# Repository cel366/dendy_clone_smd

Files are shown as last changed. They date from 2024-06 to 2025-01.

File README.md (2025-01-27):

# Деndи
Конструкция 8-ми битной приставки ,клона famicom. Максимально элементы применены для поверхностного монтажа . Печатная плата разработана для изготовления в домашних условиях ,поэтому для соединения дорожек на разных слоях использованы переходные отверстия ,для соединениями перемычками .  в папке FAB/lut два файла svg  с слоями верхним(уже от зеркаленным) и нижним  

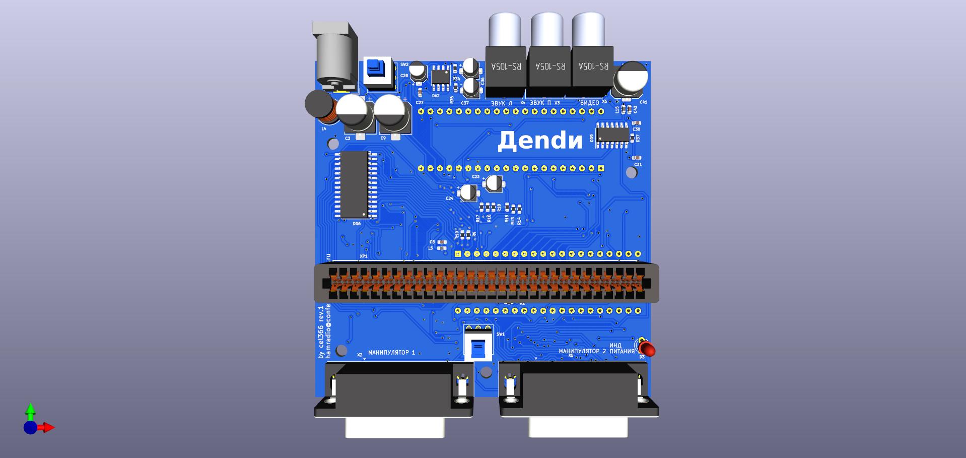
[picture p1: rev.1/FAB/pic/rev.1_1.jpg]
rev.1_1

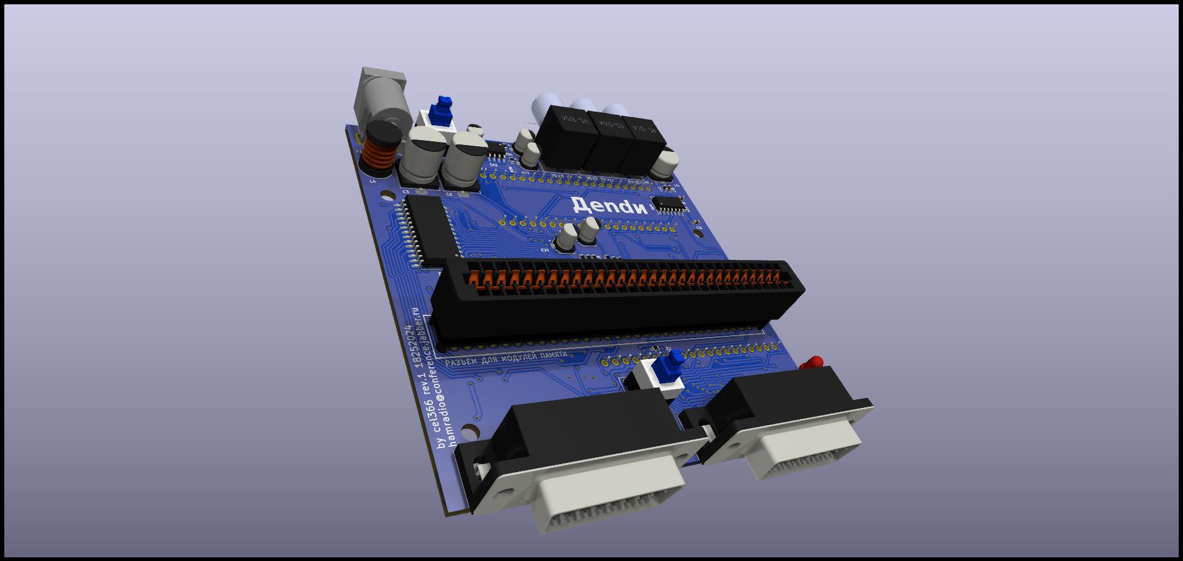
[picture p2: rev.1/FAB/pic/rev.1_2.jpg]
rev.1_2

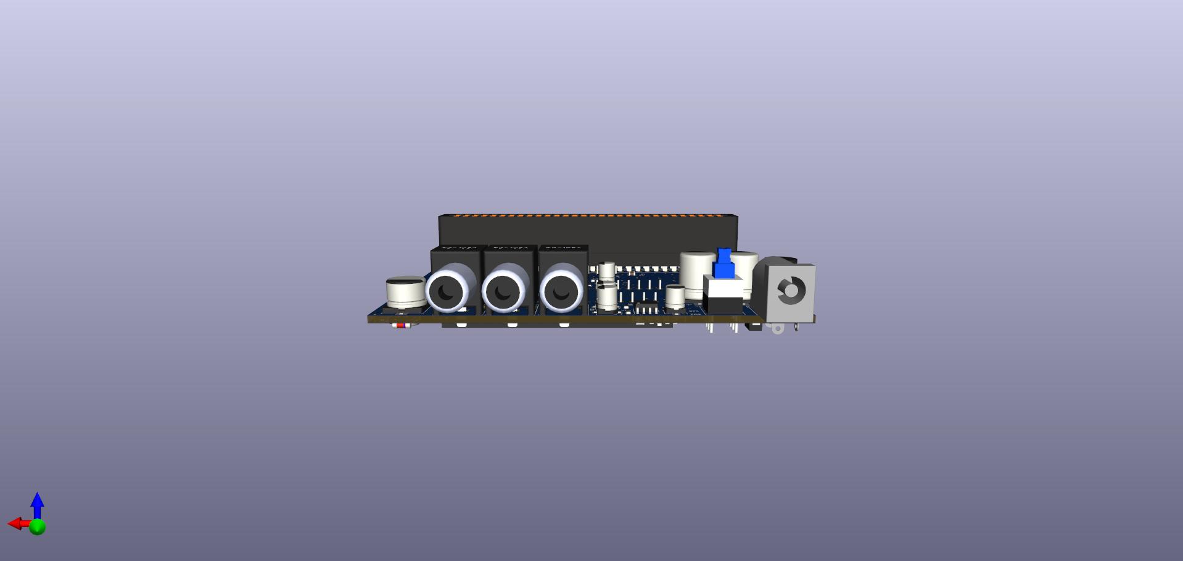
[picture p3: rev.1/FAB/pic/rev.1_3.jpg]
rev.1_3

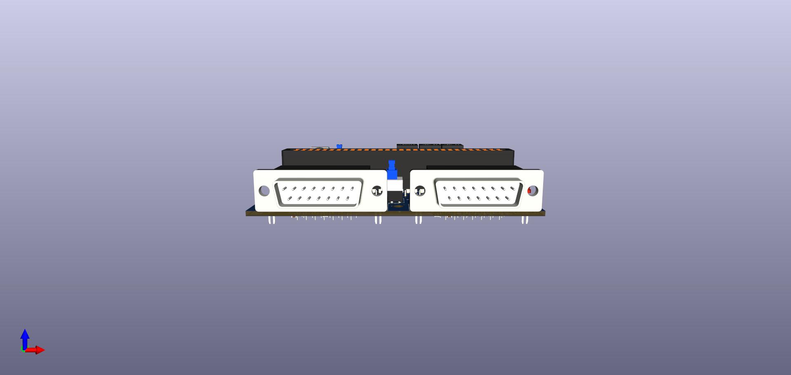
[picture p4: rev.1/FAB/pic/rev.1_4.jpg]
rev.1_4

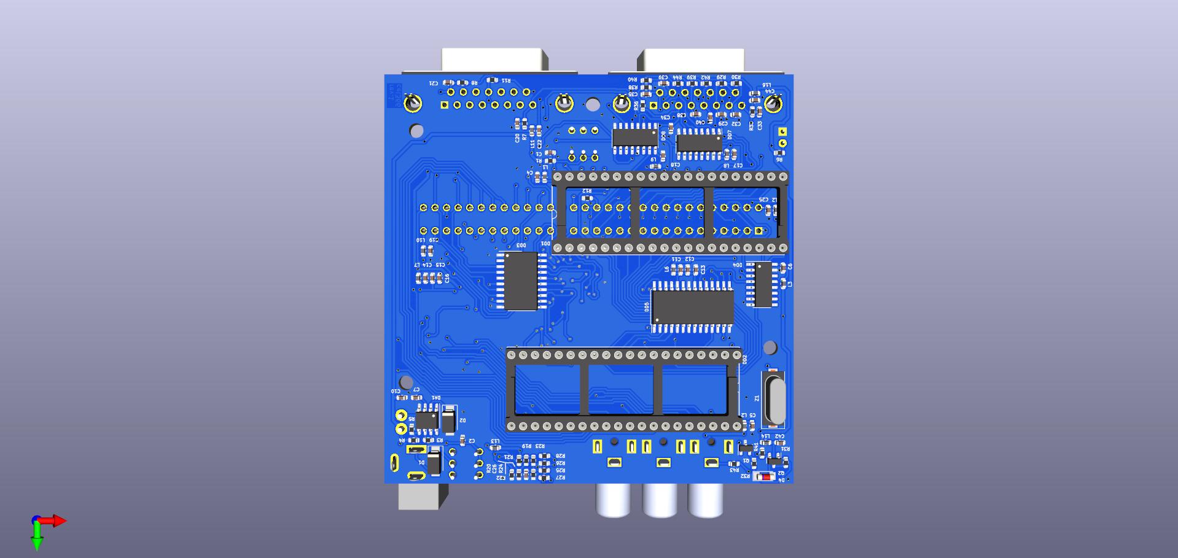
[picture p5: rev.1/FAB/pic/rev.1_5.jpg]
rev.1_5


Плата размером 90х90 ,чтобы можно было потом распечатать на принтере EasyThreeD K9 , у которого печатающая поверхность  100х100,корпус.

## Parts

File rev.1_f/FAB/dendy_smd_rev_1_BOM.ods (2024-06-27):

Prj: | rev.1.csv |  |  |  | Board Qty: | 1
Co.: |  |  |  |  | Unit Cost: | $0,00
Prj date: | 2024-06-27 15:57:16 (file) |  |  |  | Total Cost: | $0,00
$ date: | 2024-06-27 16:00:30
Global Part Info
Refs | Value | Footprint | Manf# | Qty | Unit$ | Ext$
C1 | 0.47uF | C_0603_1608Metric | CC0603KRX7R9BB474 | 1
C2,C4-C6,C8,C10-C19,C22,C25-C27,C42-C44 | 0.1uF | C_0603_1608Metric | CC0603ZRY5V9BB104 | 22
C3 | 220uFx25V | CP_Elec_8x10.5 | VT221M1EJBKJ0810VBK | 1
C7 | 470p | C_0603_1608Metric | CC0603KRX7R9BB471 | 1
C9 | 470uFx6.3V | CP_Elec_8x10.5 | TS13C00J471MJT000R | 1
C20,C21,C29,C32-C35,C38-C40 | 330pF | C_0603_1608Metric | CC0603JRNPO9BN331 | 10
C23,C24,C28,C36,C37 | 10uFx16V | CP_Elec_4x5.4 | CK1C100M-CRC54 | 5
C30,C31 | 22pF | C_0603_1608Metric | CC0603JRNPO9BN220 | 2
C41 | 220uFx10V | CP_Elec_8x6.5 | VCT227M010S0ANG10L | 1
D1,D2 | SS14 | D_SMA | SS14 | 2
D3 | LED_POWER | LED_D3.0mm | L-7104EC@KGB | 1
D4 | BAS85 | D_MiniMELF | BAS85 | 1
DA1 | MC34063AD | SOIC-8_3.9x4.9mm_P1.27mm | MC34063AD | 1
DA2 | LM358 | SOIC-8_3.9x4.9mm_P1.27mm | LM358D | 1
DD1 | UA6527 | DIP-40_W15.24mm_Socket | UA6527P | 1
DD2 | UA6538 | DIP-40_W15.24mm_Socket | UA6538 | 1
DD3 | 74HC373 | SO-20_12.8x7.5mm_P1.27mm | 74HC373D | 1
DD4 | 74HC139 | SO-16_3.9x9.9mm_P1.27mm | 74HC139D | 1
DD5,DD6 | IS62C256AL-45ULI-TR | SOIC-28W_7.5x17.9mm_P1.27mm | IS62C256AL-45ULI | 2
DD7,DD8 | 74HC368N | SO-16_3.9x9.9mm_P1.27mm | 74HC368D | 2
DD9 | 74LS04 | SO-14_3.9x8.65mm_P1.27mm | SN74LS04D | 1
L1-L3,L5-L16 | BLM18EG221SN1D | L_0603_1608Metric | BLM18EG221SN1D | 15
L4 | 220uH | L_Radial_D7.0mm_P3.00mm | RLB0914-221KL | 1
Q1 | BC857 | SOT-23 | BC857B | 1
Q2 | BC817 | SOT-23 | BC817-25 | 1
R1,R2,R7,R8,R11,R27-R30,R33,R36,R38-R40,R42,R44 | 10K | R_0603_1608Metric | RC0603FR-0710KL | 16
R3 | 0.12R | R_0603_1608Metric | RL0603FR-070R1L | 1
R4 | 3K6 | R_0603_1608Metric | RC0603FR-073K6L | 1
R5 | 1K2 | R_0603_1608Metric | RC0603FR-071K2L | 1
R6 | 330R | R_0603_1608Metric | RC0603FR-07330RL | 1
R9,R10,R43 | 75R | R_0603_1608Metric | RC0603FR-0775RL | 3
R12,R31 | 2K2 | R_0603_1608Metric | RC0603FR-072K2L | 2
R13,R17 | 2K | R_0603_1608Metric | RC0603FR-072KL | 2
R14,R25,R26 | 1K | R_0603_1608Metric | RC0603FR-071KL | 3
R15,R18-R22 | 4K7 | R_0603_1608Metric | RC0603FR-074K7L | 6
R16 | 1K8 | R_0603_1608Metric | RC0603FR-071K8L | 1
R23,R24 | 510R | R_0603_1608Metric | RC0603FR-07510RL | 2
R32 | 220R | R_0603_1608Metric | RC0603FR-07220RL | 1
R34,R35 | 1R | R_0603_1608Metric | RC0603FR-071RL | 2
R37 | 4M7 | R_0603_1608Metric | RC0603FR-074M7L | 1
R41 | 68R | R_0603_1608Metric | RC0603FR-0768RL | 1
SW1 | RESET | KLS7_P8X8 | KLS7-P8.0*8.0-0 | 1
SW2 | BUT_POWER | KLS7_P8X8 | KLS7-P8.0*8.0-1 | 1
X1 | POWER | BarrelJack_Wuerth_6941xx301002 | KLS1-DC-005A-2.0 | 1
X2 | Манипулятор_1 | DSUB-15_Male_Horizontal_P2.77x2.84mm_EdgePinOffset4.94mm_Housed_MountingHolesOffset7.48mm | DS1037-15-MNAKT74-0CC | 1
X3 | AUDIO_1 | RCA-105 | RCA-103P | 1
X4 | AUDIO_2 | RCA-105 | RCA-103P | 1
X5 | Манипулятор_2 | DSUB-15_Male_Horizontal_P2.77x2.84mm_EdgePinOffset4.94mm_Housed_MountingHolesOffset7.48mm | DS1037-15-MNAKT74-0CC | 1
X6 | VIDEO | RCA-105 | RCA-103P | 1
XP1 | SLOT_CARTRIGE | 60 PIN FAMICOM CARTRIDGE SLOT | KLS1-603C-62-S | 1
Z1 | 26.601712 Mhz | Crystal_SMD_HC49-SD | 26.601712M 20PF 30PPM | 1
KiCost® v1.1.19

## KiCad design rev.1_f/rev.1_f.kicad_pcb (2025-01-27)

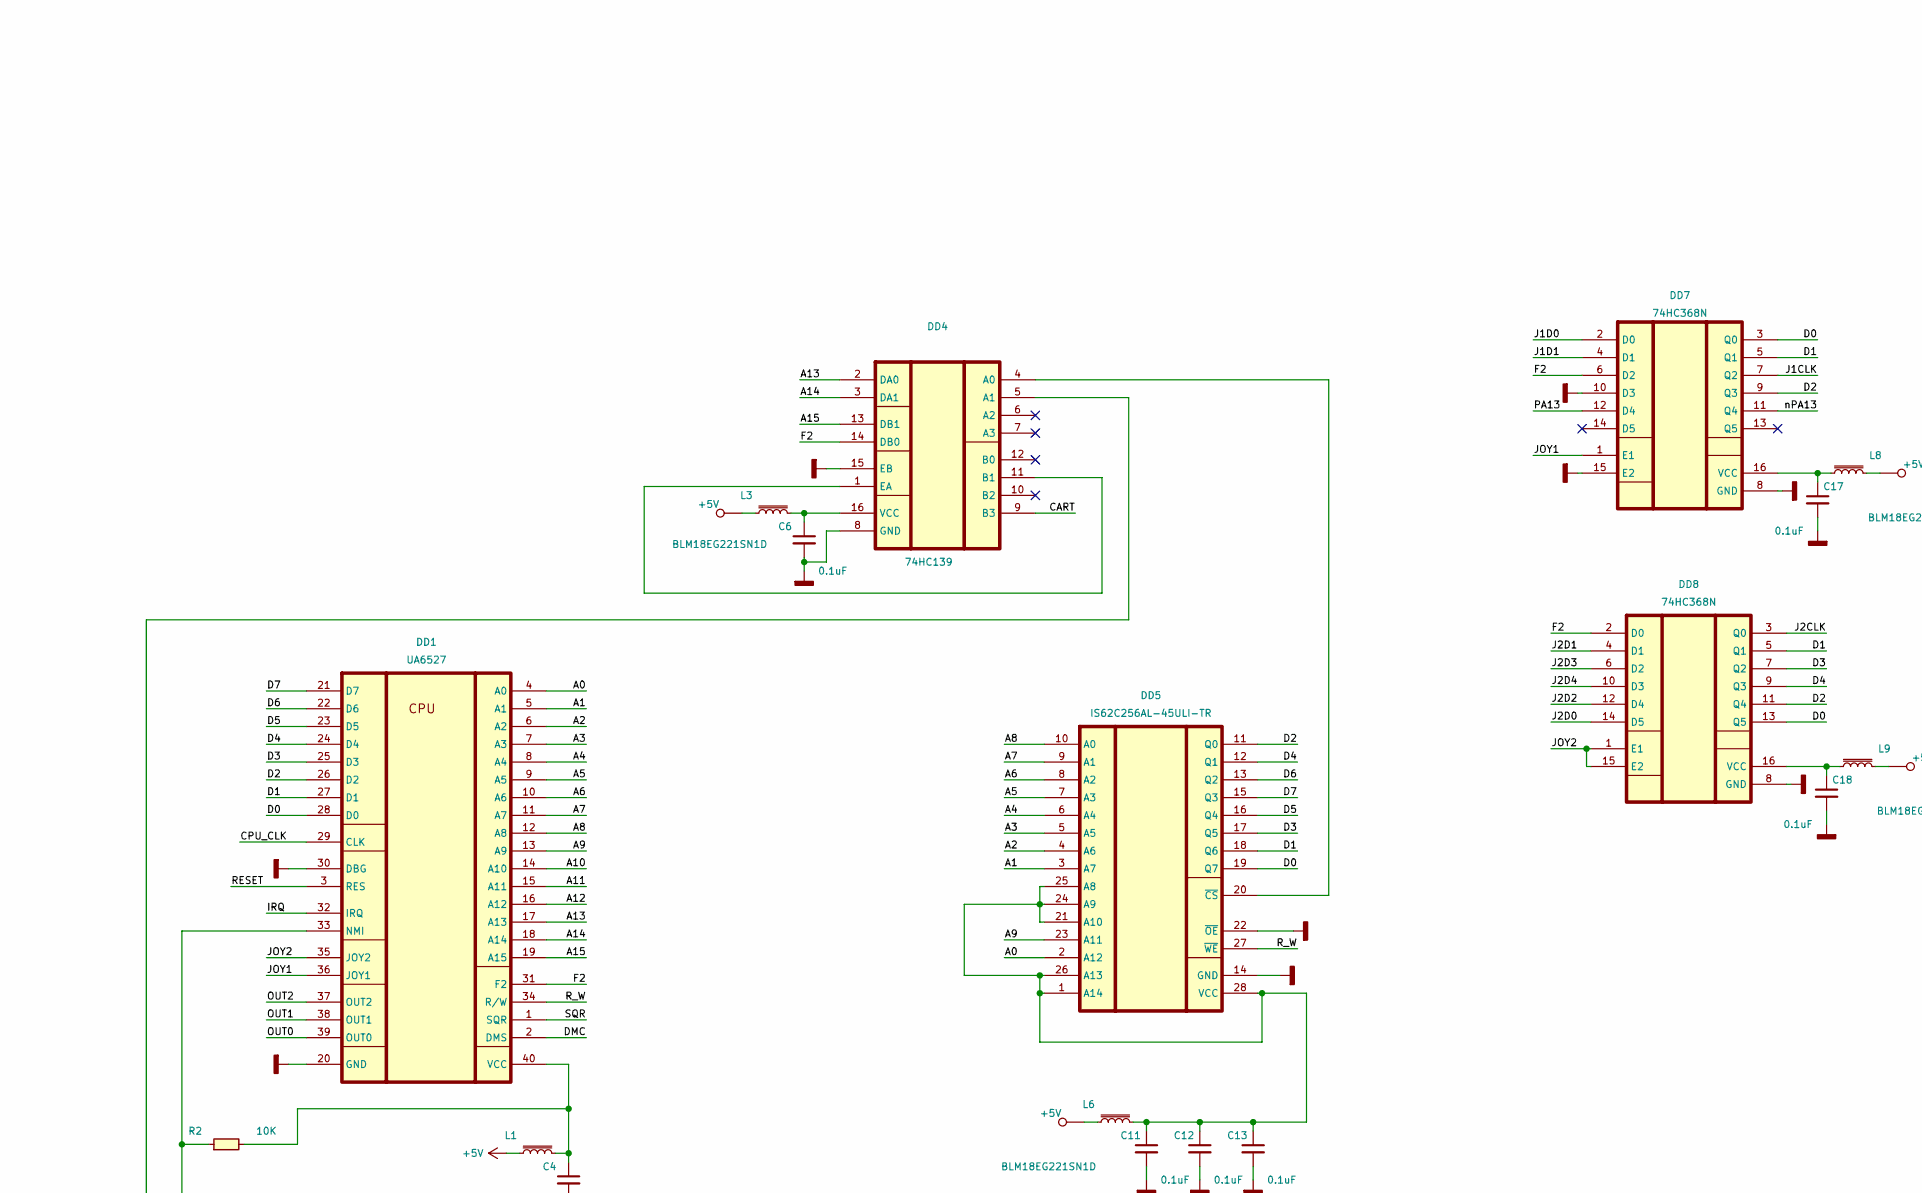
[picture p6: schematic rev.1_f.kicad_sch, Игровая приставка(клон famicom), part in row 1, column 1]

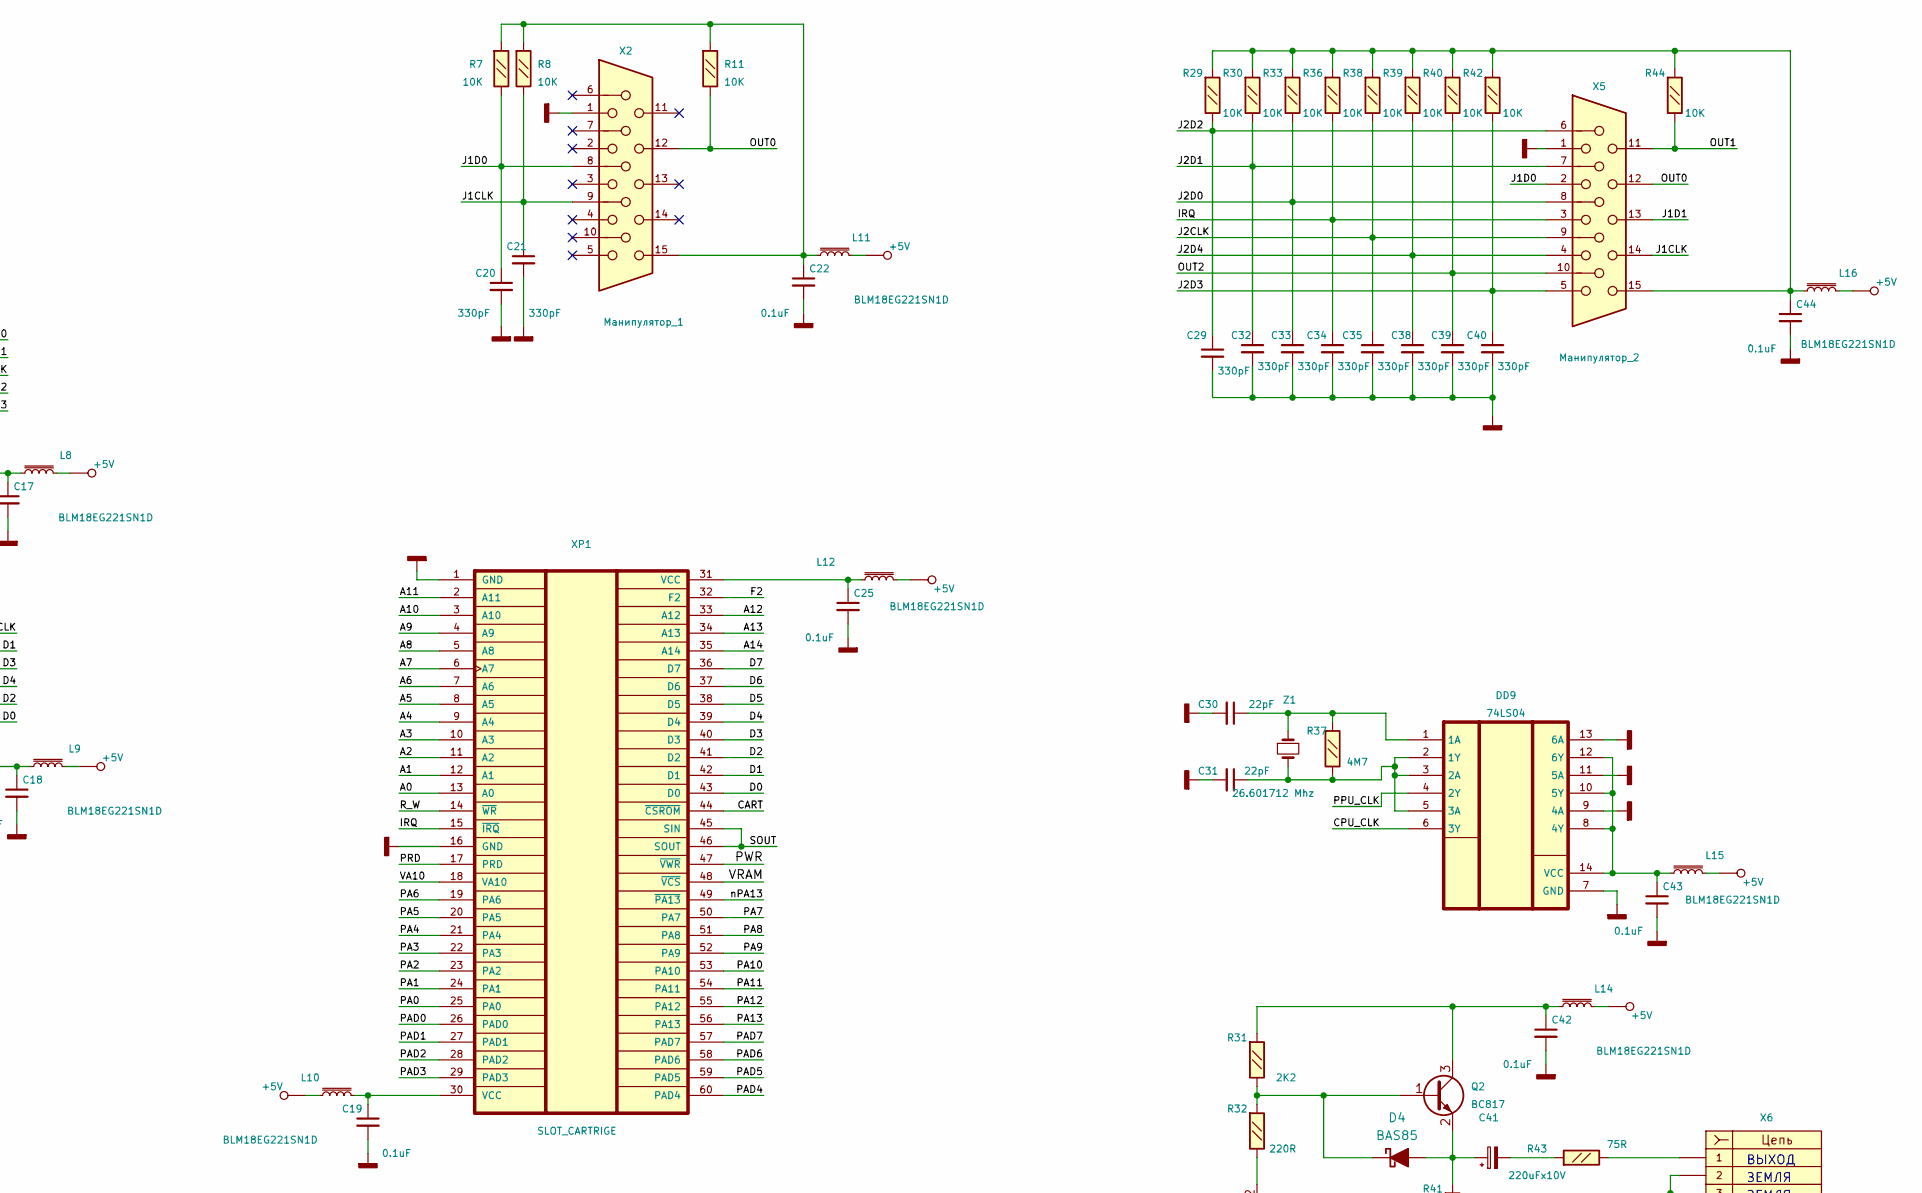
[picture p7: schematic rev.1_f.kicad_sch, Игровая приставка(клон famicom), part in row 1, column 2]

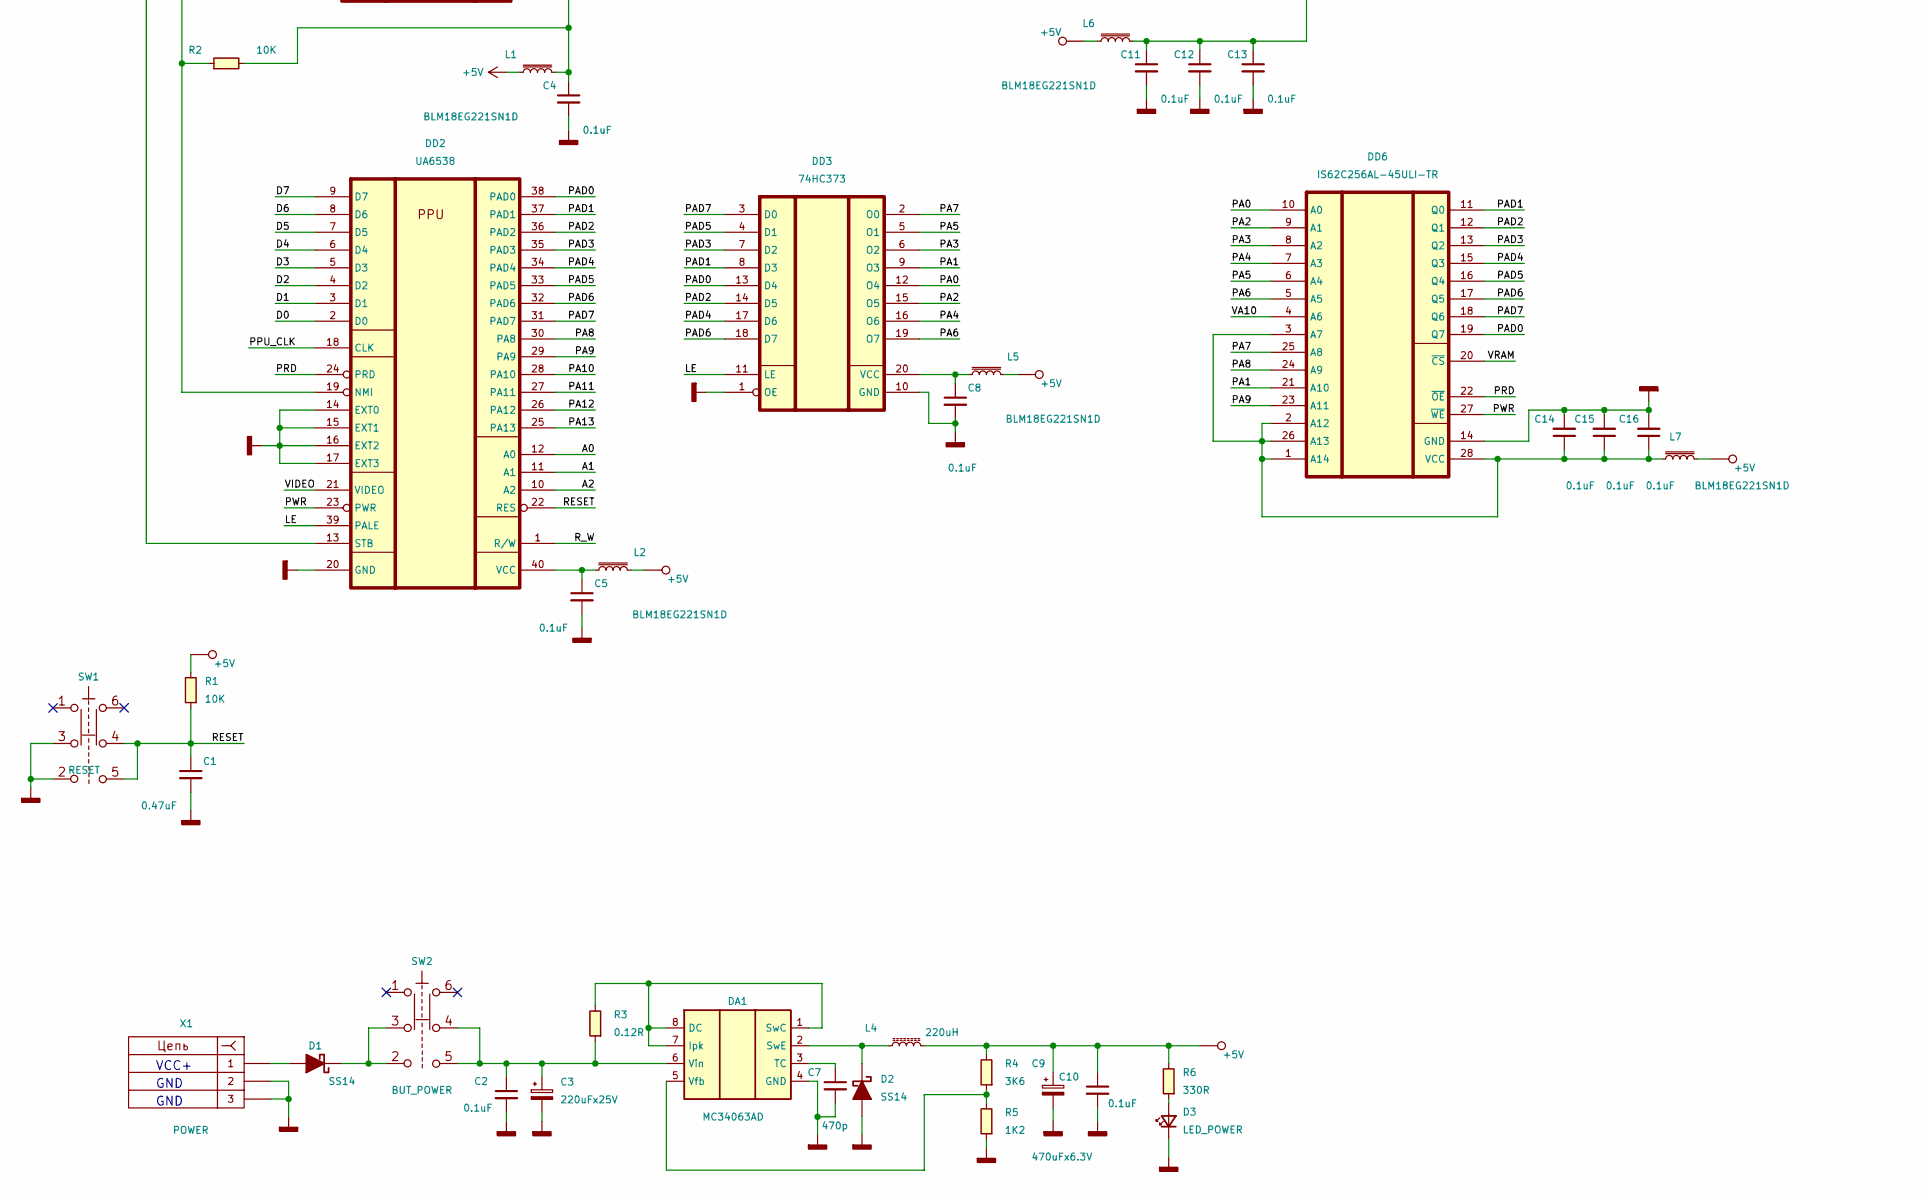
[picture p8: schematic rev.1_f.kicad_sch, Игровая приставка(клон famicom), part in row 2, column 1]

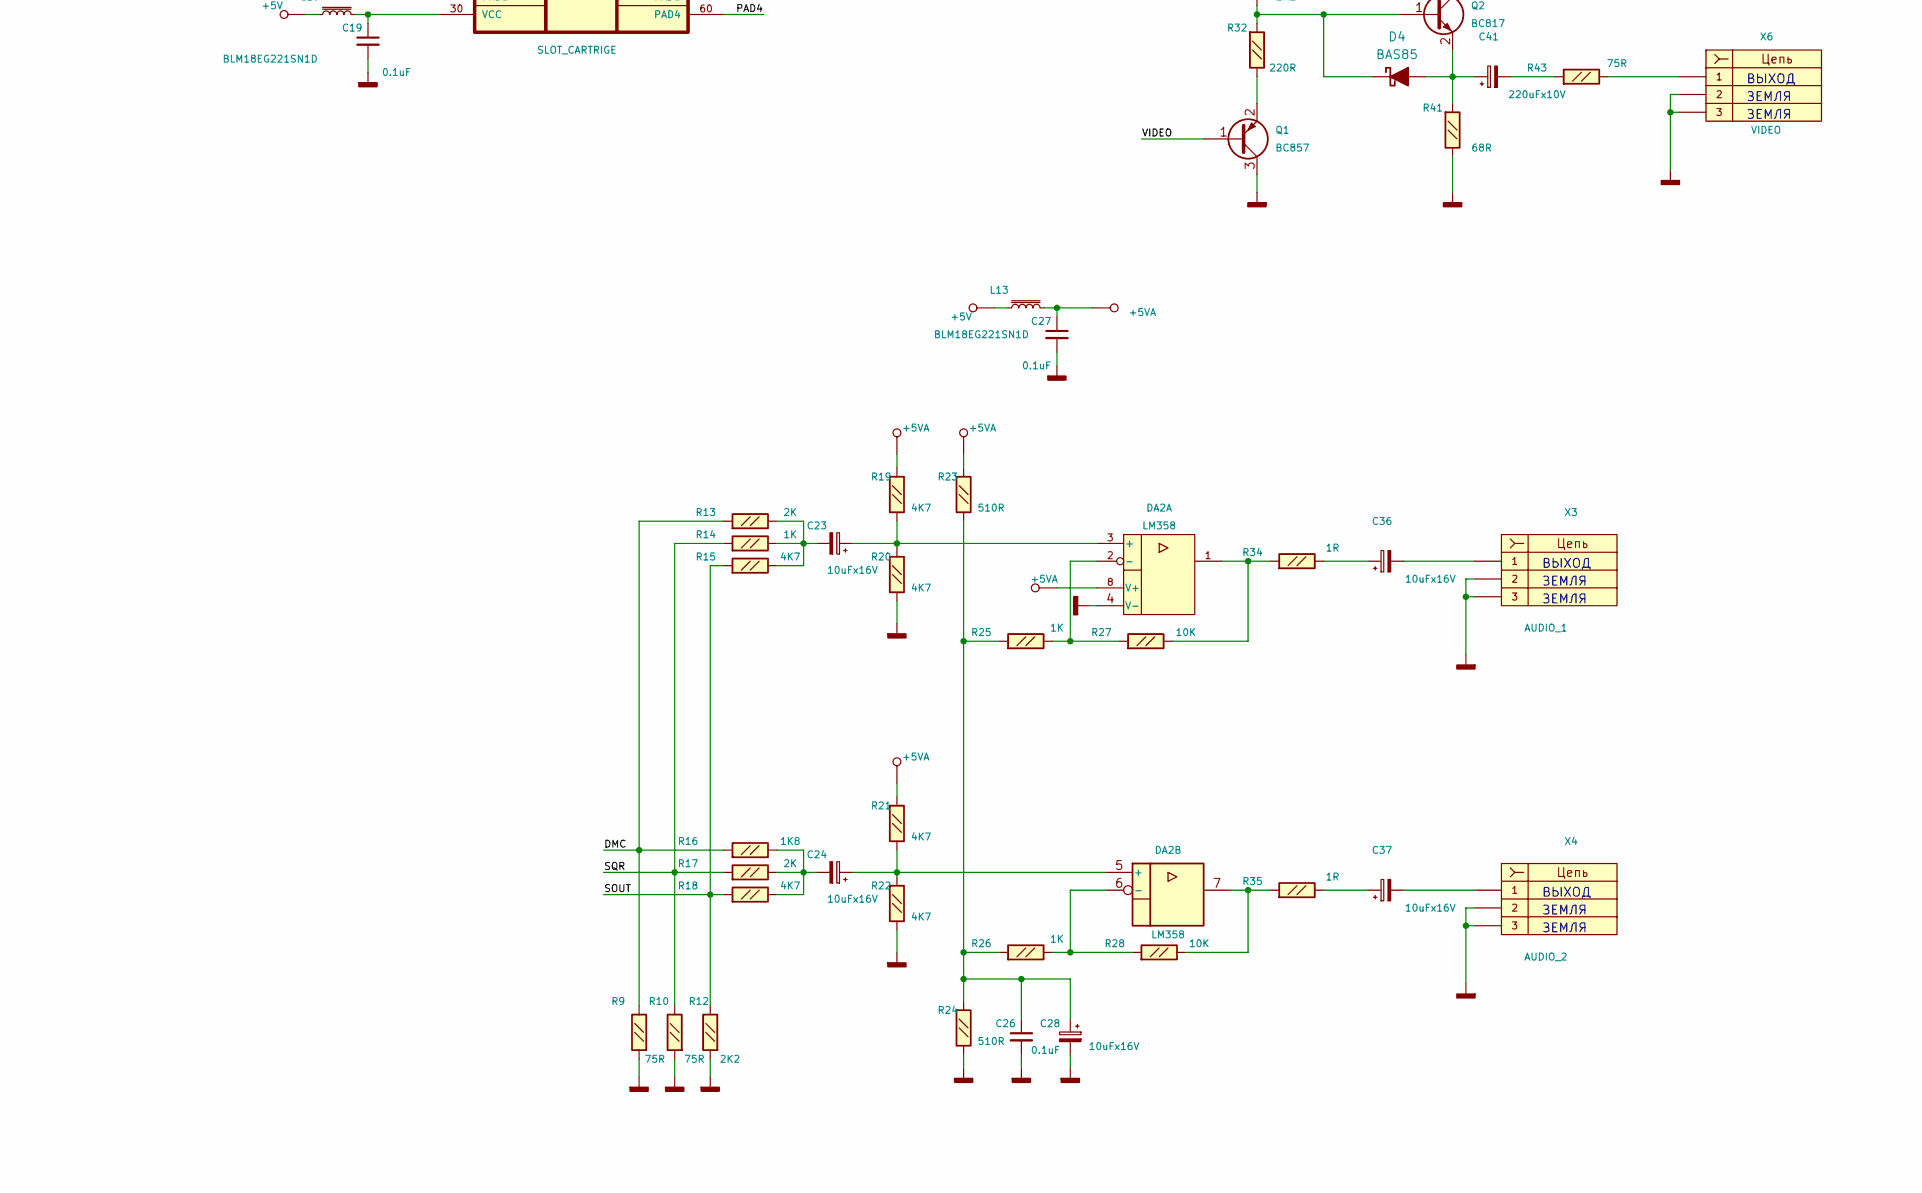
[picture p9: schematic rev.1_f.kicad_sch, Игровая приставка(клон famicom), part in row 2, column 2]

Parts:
C1: 0.47uF; C_0603_1608Metric
C2, C4, C5, C6, C8, C10, C11, C12, C13, C14, C15, C16, C17, C18, C19, C22, C25, C26, C27, C42, C43, C44: 0.1uF; C_0603_1608Metric
C3: 220uFx25V; CP_Elec_8x10.5
C7: 470p; C_0603_1608Metric
C9: 470uFx6.3V; CP_Elec_8x10.5
C20, C21, C29, C32, C33, C34, C35, C38, C39, C40: 330pF; C_0603_1608Metric
C23, C24, C28, C36, C37: 10uFx16V; CP_Elec_4x5.4
C30, C31: 22pF; C_0603_1608Metric
C41: 220uFx10V; CP_Elec_8x6.5
D1, D2: SS14; D_SMA
D3: LED_POWER; LED_D3.0mm
D4: BAS85; D_MiniMELF
DA1: MC34063AD; SOIC-8_3.9x4.9mm_P1.27mm
DA2: LM358; SOIC-8_3.9x4.9mm_P1.27mm
DD1: UA6527; DIP-40_W15.24mm_Socket
DD2: UA6538; DIP-40_W15.24mm_Socket
DD3: 74HC373; SO-20_12.8x7.5mm_P1.27mm
DD4: 74HC139; SO-16_3.9x9.9mm_P1.27mm
DD5, DD6: IS62C256AL-45ULI-TR; SOIC-28W_7.5x17.9mm_P1.27mm
DD7, DD8: 74HC368N; SO-16_3.9x9.9mm_P1.27mm
DD9: 74LS04; SO-14_3.9x8.65mm_P1.27mm
L1, L2, L3, L5, L6, L7, L8, L9, L10, L11, L12, L13, L14, L15, L16: BLM18EG221SN1D; L_0603_1608Metric
L4: 220uH; L_Radial_D7.0mm_P3.00mm
Q1: BC857; SOT-23
Q2: BC817; SOT-23
R1, R2, R7, R8, R11, R27, R28, R29, R30, R33, R36, R38, R39, R40, R42, R44: 10K; R_0603_1608Metric
R3: 0.12R; R_0603_1608Metric
R4: 3K6; R_0603_1608Metric
R5: 1K2; R_0603_1608Metric
R6: 330R; R_0603_1608Metric
R9, R10, R43: 75R; R_0603_1608Metric
R12, R31: 2K2; R_0603_1608Metric
R13, R17: 2K; R_0603_1608Metric
R14, R25, R26: 1K; R_0603_1608Metric
R15, R18, R19, R20, R21, R22: 4K7; R_0603_1608Metric
R16: 1K8; R_0603_1608Metric
R23, R24: 510R; R_0603_1608Metric
R32: 220R; R_0603_1608Metric
R34, R35: 1R; R_0603_1608Metric
R37: 4M7; R_0603_1608Metric
R41: 68R; R_0603_1608Metric
SW1: RESET; KLS7_P8X8
SW2: BUT_POWER; KLS7_P8X8
X1: POWER; BarrelJack_Wuerth_6941xx301002
X2: Манипулятор_1; DSUB-15_Male_Horizontal_P2.77x2.84mm_EdgePinOffset4.94mm_Ho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
X3: AUDIO_1; RCA-105
X4: AUDIO_2; RCA-105
X5: Манипулятор_2; DSUB-15_Male_Horizontal_P2.77x2.84mm_EdgePinOffset4.94mm_Ho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
X6: VIDEO; RCA-105
XP1: SLOT_CARTRIGE; 60 PIN FAMICOM CARTRIDGE SLOT
Z1: 26.601712 Mhz; Crystal_SMD_HC49-SD

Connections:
+5V: C9.1, C10.1, L1.1, L2.1, L3.1, L4.2, L5.1, L6.1, L7.1, L8.1, L9.1, L10.1, L11.1, L12.1, L13.1, L14.1, L15.1, L16.1, R1.2, R4.2, R6.2
+5VA: C27.1, DA2.8 (V+), L13.2, R19.2, R21.2, R23.2
/A0: DD1.4 (A0), DD2.12 (A0), DD5.2 (A12), XP1.13 (A0)
/A1: DD1.5 (A1), DD2.11 (A1), DD5.3 (A7), XP1.12 (A1)
/A2: DD1.6 (A2), DD2.10 (A2), DD5.4 (A6), XP1.11 (A2)
/A3: DD1.7 (A3), DD5.5 (A5), XP1.10 (A3)
/A4: DD1.8 (A4), DD5.6 (A4), XP1.9 (A4)
/A5: DD1.9 (A5), DD5.7 (A3), XP1.8 (A5)
/A6: DD1.10 (A6), DD5.8 (A2), XP1.7 (A6)
/A7: DD1.11 (A7), DD5.9 (A1), XP1.6 (A7)
/A8: DD1.12 (A8), DD5.10 (A0), XP1.5 (A8)
/A9: DD1.13 (A9), DD5.23 (A11), XP1.4 (A9)
/A10: DD1.14 (A10), XP1.3 (A10)
/A11: DD1.15 (A11), XP1.2 (A11)
/A12: DD1.16 (A12), XP1.33 (A12)
/A13: DD1.17 (A13), DD4.2 (DA0), XP1.34 (A13)
/A14: DD1.18 (A14), DD4.3 (DA1), XP1.35 (A14)
/A15: DD1.19 (A15), DD4.13 (DB1)
/CART: DD4.9 (B3), XP1.44 (~CSROM)
/CPU_CLK: DD1.29 (CLK), DD9.6 (3Y)
/D0: DD1.28 (D0), DD2.2 (D0), DD5.19 (Q7), DD7.3 (Q0), DD8.13 (Q5), XP1.43 (D0)
/D1: DD1.27 (D1), DD2.3 (D1), DD5.18 (Q6), DD7.5 (Q1), DD8.5 (Q1), XP1.42 (D1)
/D2: DD1.26 (D2), DD2.4 (D2), DD5.11 (Q0), DD7.9 (Q3), DD8.11 (Q4), XP1.41 (D2)
/D3: DD1.25 (D3), DD2.5 (D3), DD5.17 (Q5), DD8.7 (Q2), XP1.40 (D3)
/D4: DD1.24 (D4), DD2.6 (D4), DD5.12 (Q1), DD8.9 (Q3), XP1.39 (D4)
/D5: DD1.23 (D5), DD2.7 (D5), DD5.16 (Q4), XP1.38 (D5)
/D6: DD1.22 (D6), DD2.8 (D6), DD5.13 (Q2), XP1.37 (D6)
/D7: DD1.21 (D7), DD2.9 (D7), DD5.15 (Q3), XP1.36 (D7)
/DMC: DD1.2 (DMS), R9.1, R13.2, R16.2
/F2: DD1.31 (F2), DD4.14 (DB0), DD7.6 (D2), DD8.2 (D0), XP1.32 (F2)
/IRQ: C34.1, DD1.32 (IRQ), R36.1, X5.3, XP1.15 (~IRQ)
/J1CLK: C21.1, DD7.7 (Q2), R8.1, X2.9, X5.14
/J1D0: C20.1, DD7.2 (D0), R7.1, X2.8, X5.2
/J1D1: DD7.4 (D1), X5.13
/J2CLK: C35.1, DD8.3 (Q0), R38.1, X5.9
/J2D0: C33.1, DD8.14 (D5), R33.1, X5.8
/J2D1: C32.1, DD8.4 (D1), R30.1, X5.7
/J2D2: C29.1, DD8.12 (D4), R29.1, X5.6
/J2D3: C40.1, DD8.6 (D2), R42.1, X5.5
/J2D4: C38.1, DD8.10 (D3), R39.1, X5.4
/JOY1: DD1.36 (JOY1), DD7.1 (E1)
/JOY2: DD1.35 (JOY2), DD8.1 (E1), DD8.15 (E2)
/LE: DD2.39 (PALE), DD3.11 (LE)
/OUT0: DD1.39 (OUT0), R11.1, X2.12, X5.12
/OUT1: DD1.38 (OUT1), R44.1, X5.11
/OUT2: C39.1, DD1.37 (OUT2), R40.1, X5.10
/PA0: DD3.12 (O4), DD6.10 (A0), XP1.25 (PA0)
/PA1: DD3.9 (O3), DD6.21 (A10), XP1.24 (PA1)
/PA2: DD3.15 (O5), DD6.9 (A1), XP1.23 (PA2)
/PA3: DD3.6 (O2), DD6.8 (A2), XP1.22 (PA3)
/PA4: DD3.16 (O6), DD6.7 (A3), XP1.21 (PA4)
/PA5: DD3.5 (O1), DD6.6 (A4), XP1.20 (PA5)
/PA6: DD3.19 (O7), DD6.5 (A5), XP1.19 (PA6)
/PA7: DD3.2 (O0), DD6.25 (A8), XP1.50 (PA7)
/PA8: DD2.30 (PA8), DD6.24 (A9), XP1.51 (PA8)
/PA9: DD2.29 (PA9), DD6.23 (A11), XP1.52 (PA9)
/PA10: DD2.28 (PA10), XP1.53 (PA10)
/PA11: DD2.27 (PA11), XP1.54 (PA11)
/PA12: DD2.26 (PA12), XP1.55 (PA12)
/PA13: DD2.25 (PA13), DD7.12 (D4), XP1.56 (PA13)
/PAD0: DD2.38 (PAD0), DD3.13 (D4), DD6.19 (Q7), XP1.26 (PAD0)
/PAD1: DD2.37 (PAD1), DD3.8 (D3), DD6.11 (Q0), XP1.27 (PAD1)
/PAD2: DD2.36 (PAD2), DD3.14 (D5), DD6.12 (Q1), XP1.28 (PAD2)
/PAD3: DD2.35 (PAD3), DD3.7 (D2), DD6.13 (Q2), XP1.29 (PAD3)
/PAD4: DD2.34 (PAD4), DD3.17 (D6), DD6.15 (Q3), XP1.60 (PAD4)
/PAD5: DD2.33 (PAD5), DD3.4 (D1), DD6.16 (Q4), XP1.59 (PAD5)
/PAD6: DD2.32 (PAD6), DD3.18 (D7), DD6.17 (Q5), XP1.58 (PAD6)
/PAD7: DD2.31 (PAD7), DD3.3 (D0), DD6.18 (Q6), XP1.57 (PAD7)
/PPU_CLK: DD2.18 (CLK), DD9.4 (2Y)
/PRD: DD2.24 (PRD), DD6.22 (~OE), XP1.17 (PRD)
/PWR: DD2.23 (PWR), DD6.27 (~WE), XP1.47 (~VWR)
/RESET: C1.1, DD1.3 (RES), DD2.22 (RES), R1.1, SW1.4, SW1.5
/R_W: DD1.34 (R/W), DD2.1 (R/W), DD5.27 (~WE), XP1.14 (~WR)
/SOUT: R12.1, R15.2, R18.2, XP1.45 (SIN), XP1.46 (SOUT)
/SQR: DD1.1 (SQR), R10.1, R14.2, R17.2
/VA10: DD6.4 (A6), XP1.18 (VA10)
/VIDEO: DD2.21 (VIDEO), Q1.1 (B)
/VRAM: DD6.20 (~CS), XP1.48 (~VCS)
/nPA13: DD7.11 (Q4), XP1.49 (~PA13)
GNDD: C1.2, C2.2, C3.2, C4.2, C5.2, C6.2, C7.2, C8.2, C9.2, C10.2, C11.2, C12.2, C13.2, C14.2, C15.2, C16.2, C17.2, C18.2, C19.2, C20.2, C21.2, C22.2, C25.2, C26.2, C27.2, C28.2, C29.2, C30.2, C31.2, C32.2, C33.2, C34.2, C35.2, C38.2, C39.2, C40.2, C42.2, C43.2, C44.2, D2.2 (A), D3.1 (K), DA1.4 (GND), DA2.4 (V-), DD1.20 (GND), DD1.30 (DBG), DD2.14 (EXT0), DD2.15 (EXT1), DD2.16 (EXT2), DD2.17 (EXT3), DD2.20 (GND), DD3.1 (OE), DD3.10 (GND), DD4.8 (GND), DD4.15 (EB), DD5.14 (GND), DD5.22 (~OE), DD6.14 (GND), DD7.8 (GND), DD7.10 (D3), DD7.15 (E2), DD8.8 (GND), DD9.7 (GND), DD9.9 (4A), DD9.11 (5A), DD9.13 (6A), Q1.3 (C), R5.1, R9.2, R10.2, R12.2, R20.1, R22.1, R24.1, R41.1, SW1.2, SW1.3, X1.2, X1.3, X2.1, X3.2, X3.3, X4.2, X4.3, X5.1, X6.2, X6.3, XP1.1 (GND), XP1.16 (GND)
unnamed: C19.1, L10.2, XP1.30 (VCC)
unnamed: C22.1, L11.2, R7.2, R8.2, R11.2, X2.15
unnamed: C23.2, R13.1, R14.1, R15.1
unnamed: C24.2, R16.1, R17.1, R18.1
unnamed: C25.1, L12.2, XP1.31 (VCC)
unnamed: C26.1, C28.1, R23.1, R24.2, R25.2, R26.2
unnamed: C36.1, R34.1
unnamed: C37.1, R35.1
unnamed: C41.2, R43.2
unnamed: C44.1, L16.2, R29.2, R30.2, R33.2, R36.2, R38.2, R39.2, R40.2, R42.2, R44.2, X5.15
unnamed: D1.2 (A), X1.1
unnamed: D1.1 (K), SW2.2, SW2.3
unnamed: D2.1 (K), DA1.2 (SwE), L4.1
unnamed: D3.2 (A), R6.1
unnamed: C41.1, D4.2 (A), Q2.2 (E), R41.2
unnamed: D4.1 (K), Q2.1 (B), R31.1, R32.2
unnamed: DA1.1 (SwC), DA1.7 (Ipk), DA1.8 (DC), R3.2
unnamed: C7.1, DA1.3 (TC)
unnamed: DA1.5 (Vfb), R4.1, R5.2
unnamed: C2.1, C3.1, DA1.6 (Vin), R3.1, SW2.4, SW2.5
unnamed: DA2.1, R27.1, R34.2
unnamed: DA2.7, R28.1, R35.2
unnamed: C23.1, DA2.3 (+), R19.1, R20.2
unnamed: DA2.2 (-), R25.1, R27.2
unnamed: C24.1, DA2.5 (+), R21.1, R22.2
unnamed: DA2.6 (-), R26.1, R28.2
unnamed: DD1.33 (NMI), DD2.19 (NMI), R2.1
unnamed: C4.1, DD1.40 (VCC), L1.2, R2.2
unnamed: DD2.13 (STB), DD4.5 (A1)
unnamed: C5.1, DD2.40 (VCC), L2.2
unnamed: C8.1, DD3.20 (VCC), L5.2
unnamed: DD4.4 (A0), DD5.20 (~CS)
unnamed: DD4.1 (EA), DD4.11 (B1)
unnamed: C6.1, DD4.16 (VCC), L3.2
unnamed: C11.1, C12.1, C13.1, DD5.1 (A14), DD5.21 (A10), DD5.24 (A9), DD5.25 (A8), DD5.26 (A13), DD5.28 (VCC), L6.2
unnamed: C14.1, C15.1, C16.1, DD6.1 (A14), DD6.2 (A12), DD6.3 (A7), DD6.26 (A13), DD6.28 (VCC), L7.2
unnamed: C17.1, DD7.16 (VCC), L8.2
unnamed: C18.1, DD8.16 (VCC), L9.2
unnamed: C30.1, DD9.1 (1A), R37.2, Z1.1
unnamed: C31.1, DD9.2 (1Y), DD9.3 (2A), DD9.5 (3A), R37.1, Z1.2
unnamed: C43.1, DD9.8 (4Y), DD9.10 (5Y), DD9.12 (6Y), DD9.14 (VCC), L15.2
unnamed: Q1.2 (E), R32.1
unnamed: C42.1, L14.2, Q2.3 (C), R31.2
unnamed: C36.2, X3.1
unnamed: C37.2, X4.1
unnamed: R43.1, X6.1

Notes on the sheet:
ВЫХОД
ЗЕМЛЯ
GND
VCC+

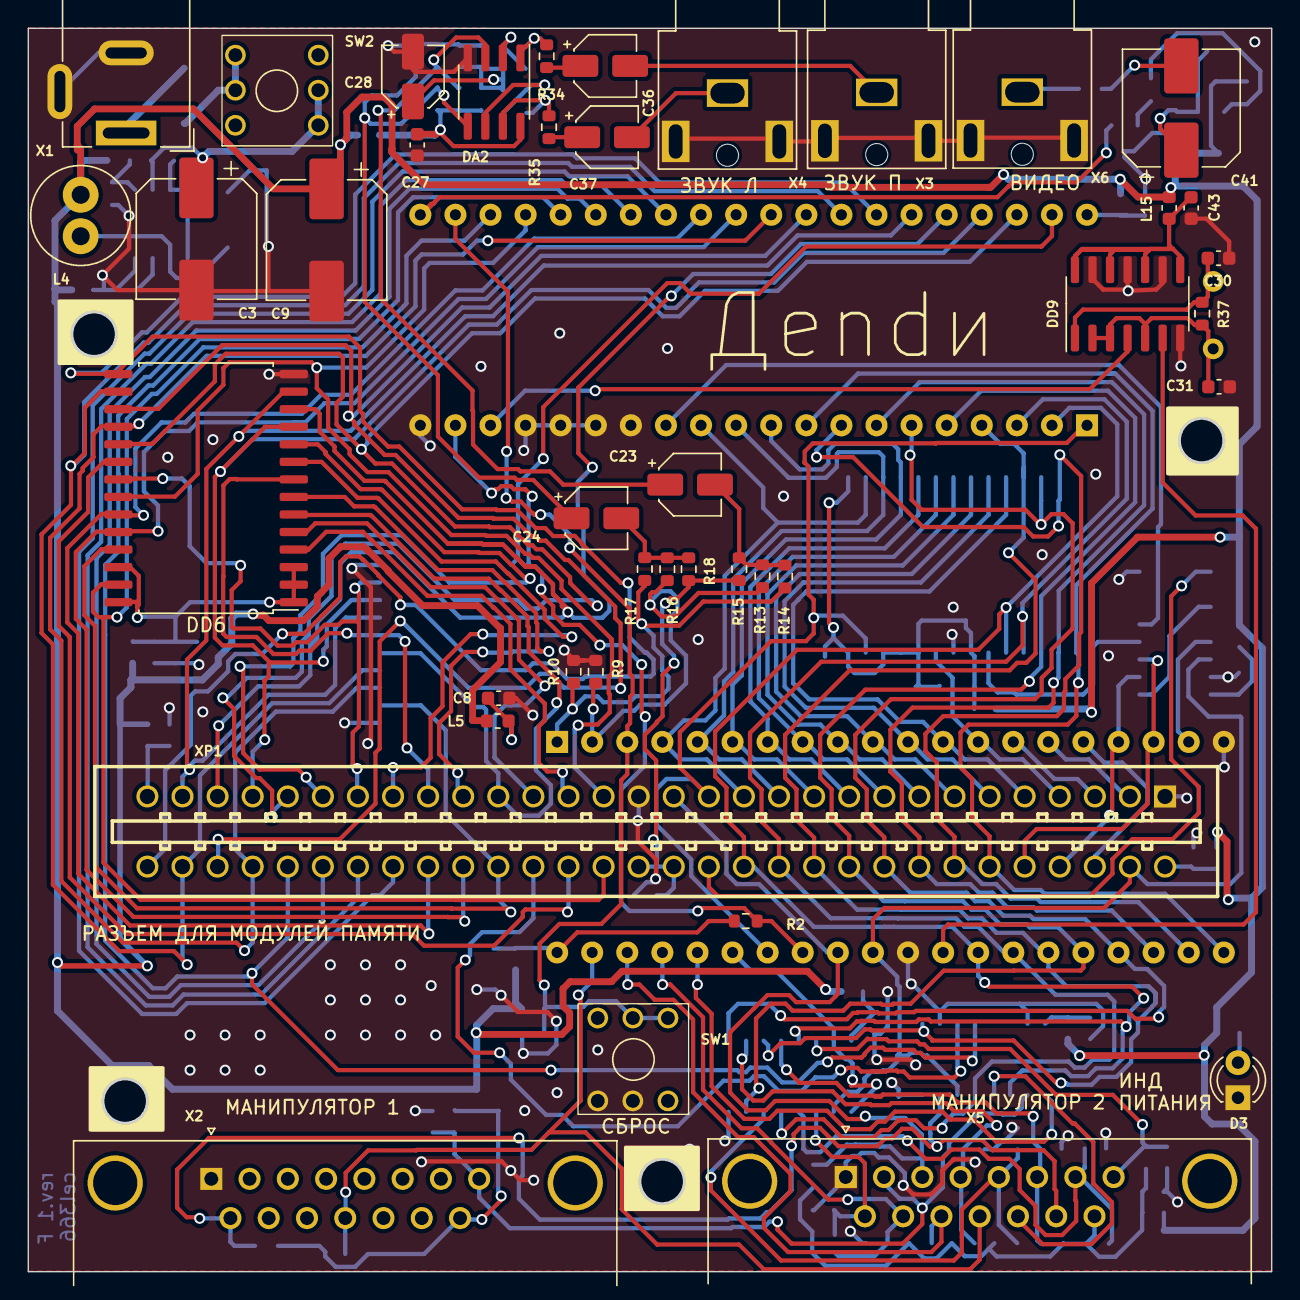
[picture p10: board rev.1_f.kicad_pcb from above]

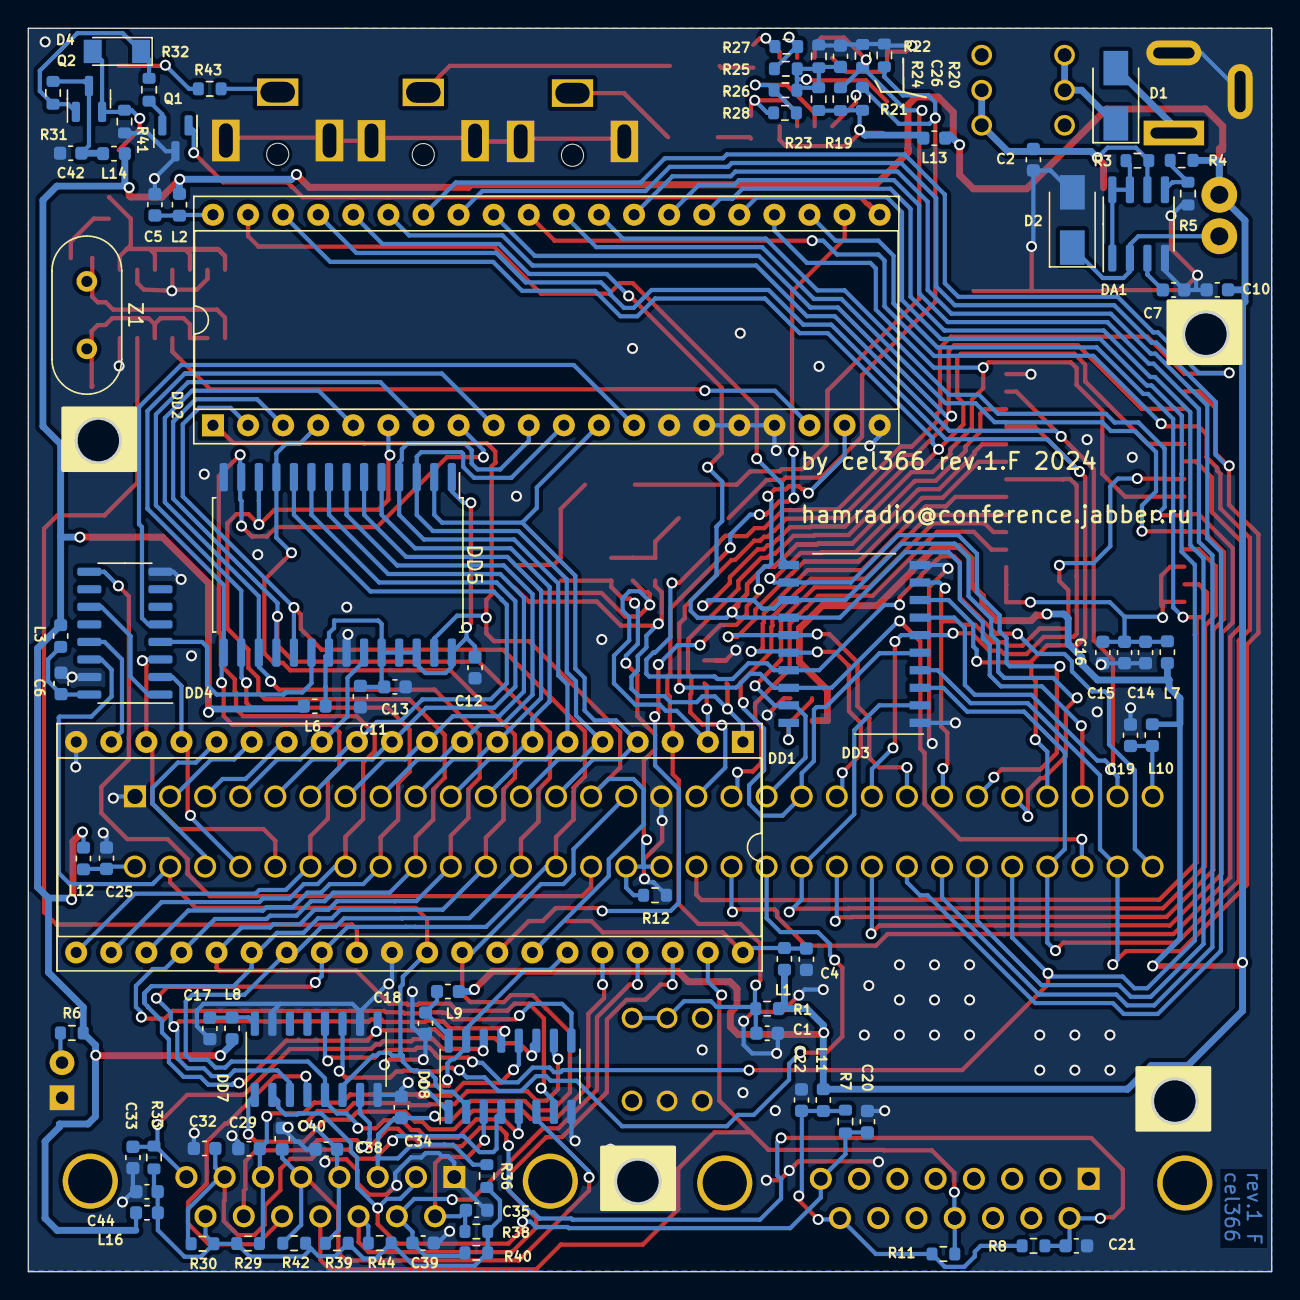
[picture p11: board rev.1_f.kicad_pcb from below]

Board: 2 copper layers, 90.0 x 90.0 mm, 131 parts (90 on the bottom side), 126 nets.

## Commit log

2022-12-22 Сделал цифровую часть и один джойстик
    [cpu_video.kicad_sch, rev.1.kicad_pcb, rev.1.kicad_sch]
2022-12-22 убрал иерархию
    [rev.1.kicad_sch]
2022-12-27 добавил документацию опринципах работы приставки и доделал джойстики
    [rev.1.kicad_sch]
2023-03-23 добавил видеоусилитель
    [rev.1.kicad_sch]
2023-03-23 добавил генератор частоты на 74ls04
    [rev.1.kicad_sch]
2023-03-23 закончил схему звукового вывода
    [rev.1.kicad_sch]
2023-06-09 Добавил стабилизатор питания и закончил схему
    [rev.1.kicad_sch]
2023-07-13 сделал контур платы и начал раставлять элементц
    [rev.1.kicad_pcb, rev.1.kicad_sch]
2023-08-26 раставил элементы приступил к трассеровке
    [rev.1.dsn, rev.1.kicad_pcb, rev.1.kicad_sch]
2024-06-18 Сделал разводку печатной платы
    [freerouting.dsn, rev.1.dsn, rev.1.kicad_pcb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]
2024-06-18 Добавил схему в pdf
2024-06-18 расставил обозначения и надписи
    [rev.1.kicad_pcb]
2024-06-18 мелкие улучшения и добавление крепежных отверстий
    [rev.1.kicad_pcb]
2024-06-27 добавил список элементов ,гербера
    [dendy_smd_rev_1_BOM.ods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]
2024-06-27 Update README.md
    описание
2025-01-27 Исправил посадочные места DD5 и DD6 заново сделал файлы svg для ЛУТ , изменил название ревизии rev.1_l
    [rev.1-B_Cu.gbl, rev.1-B_Mask.gbs, rev.1-B_Paste.gbp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]
2025-01-27 Сделал разводку для заводского исполения назвал ревия rev.1_F
    [cpu_video.kicad_sch, dendy_smd_rev_1_BOM.ods, freerouting.dsn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]
